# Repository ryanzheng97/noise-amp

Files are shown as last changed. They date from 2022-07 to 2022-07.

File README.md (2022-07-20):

# noise-amp

A very high gain (80db or x10000) differential AC signal amplifier (LNA, pre-amplifier, noise amplifier, etc.) board based on EEVBlog community design.

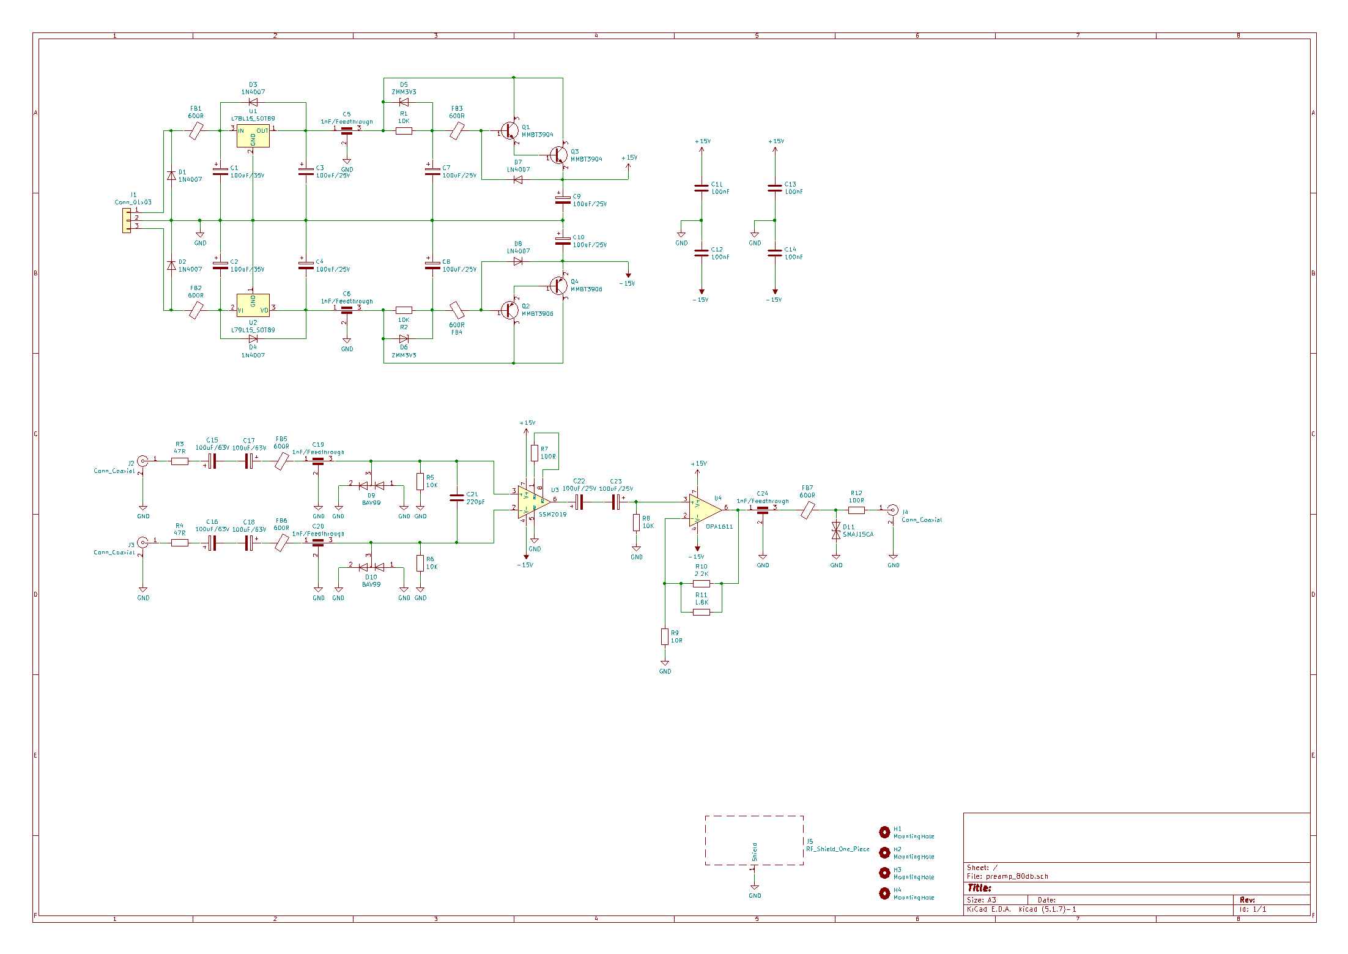
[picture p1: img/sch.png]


[Original post](https://www.eevblog.com/forum/beginners/question-about-preamp-for-measuring-noise/msg98285/#msg98285)

Board is a 100x100mm 4-layer PCB which falls into the cheap sample tier at JLCPCB or PCBWay.

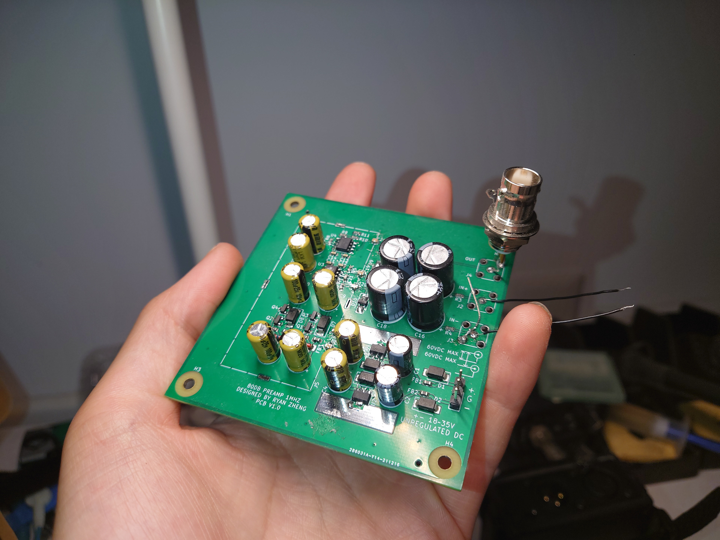
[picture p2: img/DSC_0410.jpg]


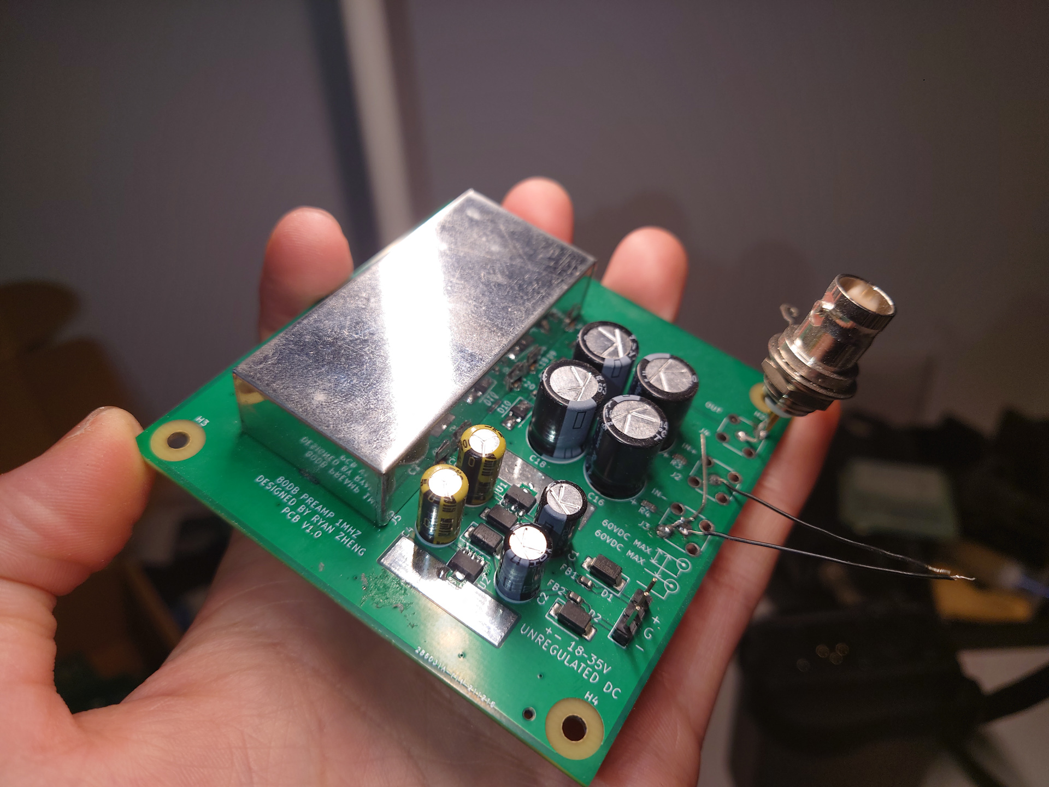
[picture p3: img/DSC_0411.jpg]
Photo of board with shielding can


# Specs
- Gain: 80db nominal
- Bandwidth: <= 1MHz
- Power: +-18 to 35VDC, unregulated
- Connector: SMA for signal input and output, 2.54mm THT pads for power input.

Test was done with a 1M to 100R resistor divider in front of the input. Signal was a sigle-ended sine wave, so one of the input is shorted to ground. Channel 3 shows original signal before resistor divider. Channel 1 shows amplified output.

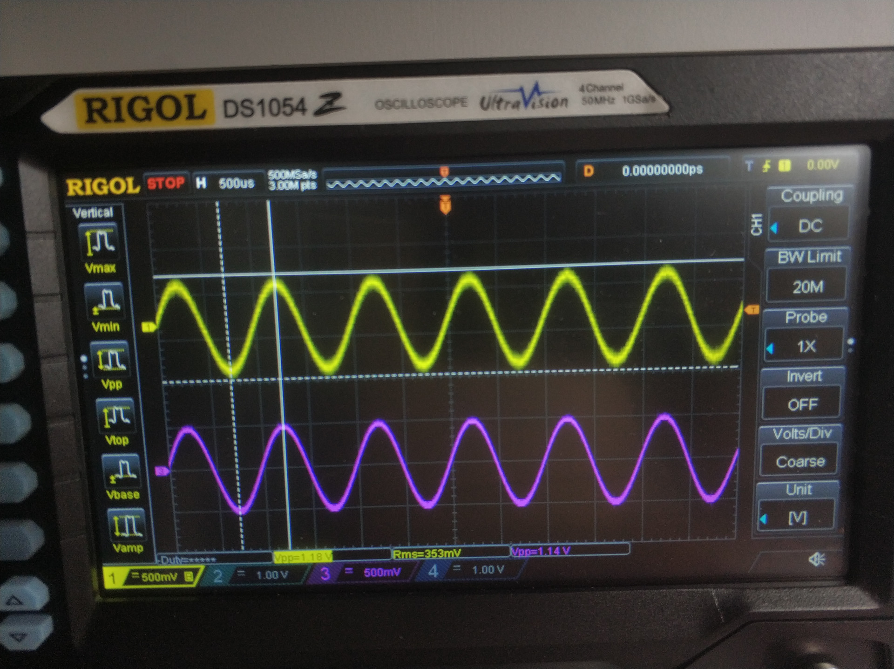
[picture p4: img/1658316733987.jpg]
Testing


# Notes
- Use high quality electrolytic capacitors
- Keep away from transformers
- You can replace op-amps with other models that you have or like
- Avoid ground loop when using
- Ground one input if using sigle-ended

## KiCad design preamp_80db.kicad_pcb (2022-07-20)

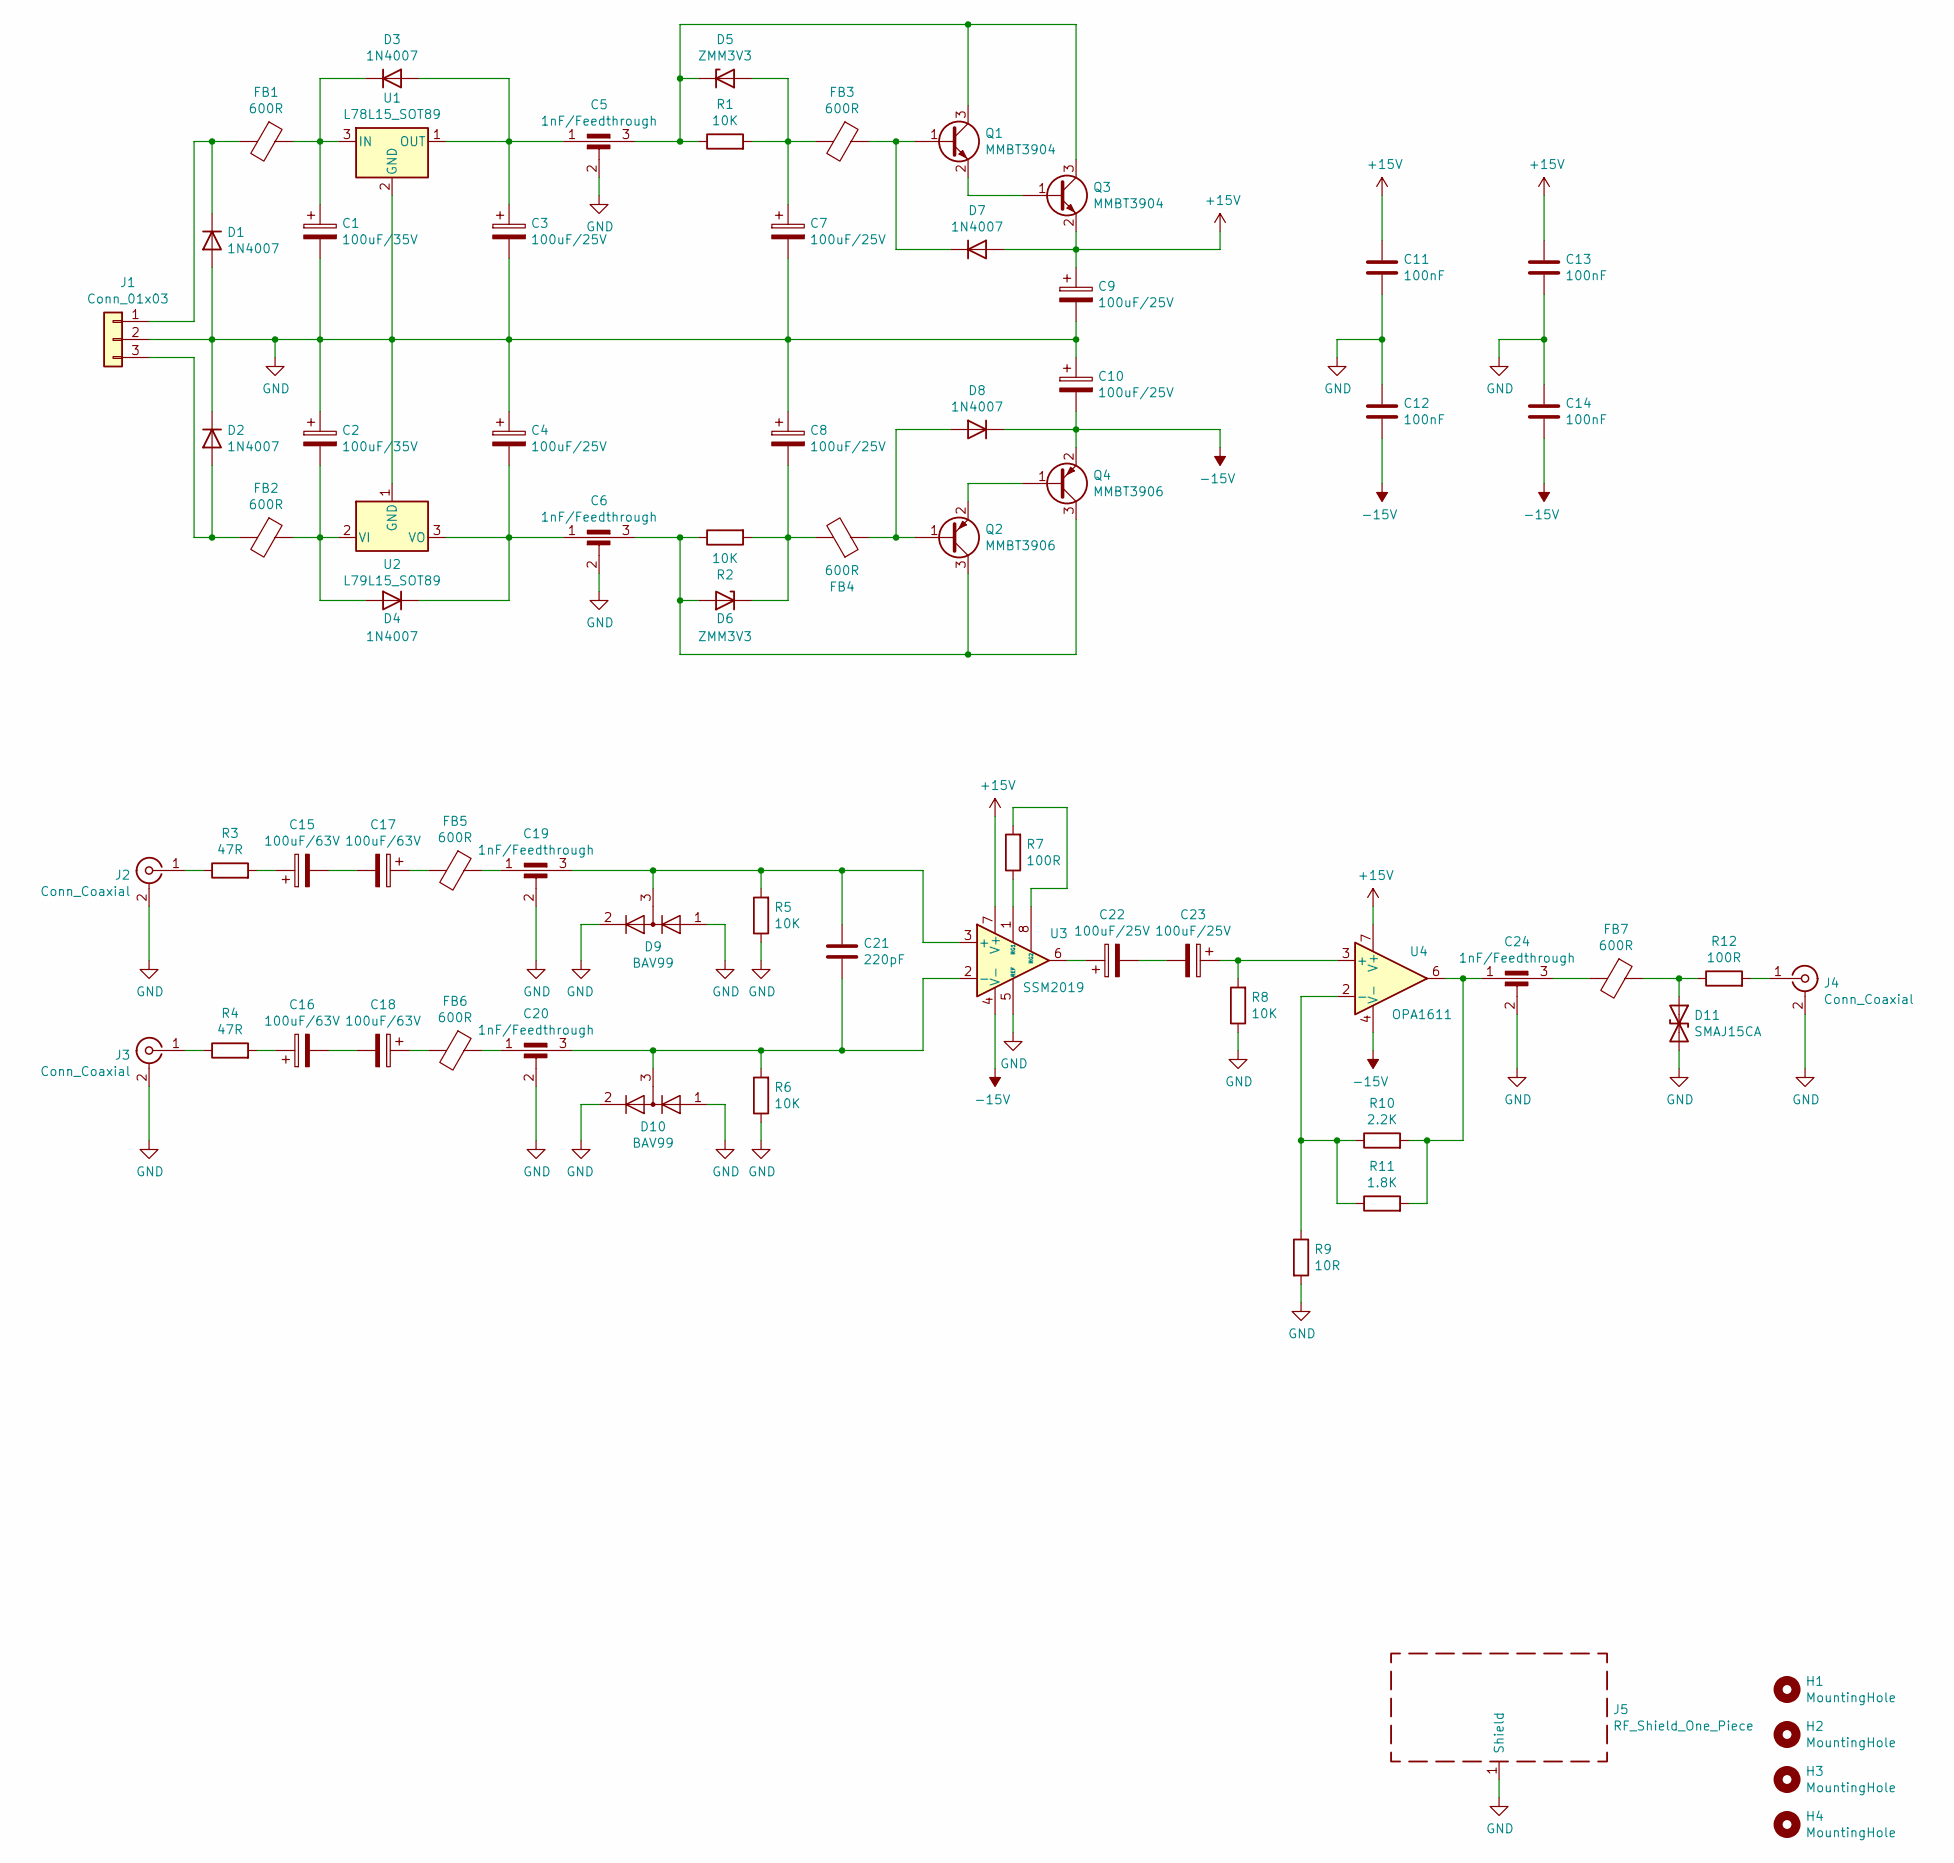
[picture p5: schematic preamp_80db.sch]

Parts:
C1, C2: 100uF/35V; CP_Radial_D6.3mm_P2.50mm
C3, C4, C7, C8, C9, C10, C22, C23: 100uF/25V; CP_Radial_D6.3mm_P2.50mm
C5, C6, C19, C20, C24: 1nF/Feedthrough; C_SMT_feedthrough_murata_0805
C11, C12, C13, C14: 100nF; C_0603_1608Metric
C15, C16, C17, C18: 100uF/63V; CP_Radial_D10.0mm_P2.50mm_P5.00mm
C21: 220pF; C_0603_1608Metric
D1, D2, D3, D4, D7, D8: 1N4007; D_SMA
D5, D6: ZMM3V3; D_MiniMELF
D9, D10: BAV99; SOT-23
D11: SMAJ15CA; D_SMA
FB1, FB2, FB3, FB4, FB5, FB6, FB7: 600R; L_0603_1608Metric
H1, H2, H3, H4: MountingHole; MountingHole_3.2mm_M3
J1: Conn_01x03; PinHeader_1x03_P2.54mm_Vertical
J2, J3, J4: Conn_Coaxial; SMA_Amphenol_132134_Vertical
J5: RF_Shield_One_Piece; Shielding_Can_THT_57x27x13mm
Q1, Q3: MMBT3904; SOT-23
Q2, Q4: MMBT3906; SOT-23
R1, R2, R5, R6, R8: 10K; R_0603_1608Metric
R3, R4: 47R; R_0603_1608Metric
R7, R12: 100R; R_0603_1608Metric
R9: 10R; R_0603_1608Metric
R10: 2.2K; R_0603_1608Metric
R11: 1.8K; R_0603_1608Metric
U1: L78L15_SOT89; SOT-89-3
U2: L79L15_SOT89; SOT-89-3
U3: SSM2019; SOIC-8_3.9x4.9mm_P1.27mm
U4: OPA1611; SOIC-8_3.9x4.9mm_P1.27mm

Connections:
+15V: C9.1, C11.1, C13.1, D7.2 (A), Q3.2 (E), U3.7 (V+), U4.7 (V+)
-15V: C10.2, C12.2, C14.2, D8.1 (K), Q4.2 (E), U3.4 (V-), U4.4 (V-)
GND: C1.2, C2.1, C3.2, C4.1, C5.2, C6.2, C7.2, C8.1, C9.2, C10.1, C11.2, C12.1, C13.2, C14.1, C19.2, C20.2, C24.2, D1.2 (A), D2.1 (K), D9.1 (K), D9.2 (A), D10.1 (K), D10.2 (A), D11.2 (A2), J1.2, J2.2 (Ext), J3.2 (Ext), J4.2 (Ext), J5.1, R5.1, R6.1, R8.1, R9.2, U1.2 (GND), U2.1 (GND), U3.5 (REF)
unnamed: C1.1, D3.1 (K), FB1.1, U1.3 (IN)
unnamed: C2.2, D4.2 (A), FB2.1, U2.2 (VI)
unnamed: C3.1, C5.1, D3.2 (A), U1.1 (OUT)
unnamed: C4.2, C6.1, D4.1 (K), U2.3 (VO)
unnamed: C5.3, D5.1 (K), Q1.3 (C), Q3.3 (C), R1.1
unnamed: C6.3, D6.2 (A), Q2.3 (C), Q4.3 (C), R2.1
unnamed: C7.1, D5.2 (A), FB3.2, R1.2
unnamed: C8.2, D6.1 (K), FB4.2, R2.2
unnamed: C15.1, R3.2
unnamed: C15.2, C17.2
unnamed: C16.1, R4.2
unnamed: C16.2, C18.2
unnamed: C17.1, FB5.2
unnamed: C18.1, FB6.2
unnamed: C19.1, FB5.1
unnamed: C19.3, C21.1, D9.3 (K), R5.2, U3.3 (+)
unnamed: C20.1, FB6.1
unnamed: C20.3, C21.2, D10.3 (K), R6.2, U3.2 (-)
unnamed: C22.1, U3.6
unnamed: C22.2, C23.2
unnamed: C23.1, R8.2, U4.3 (+)
unnamed: C24.1, R10.2, R11.2, U4.6
unnamed: C24.3, FB7.2
unnamed: D1.1 (K), FB1.2, J1.1
unnamed: D2.2 (A), FB2.2, J1.3
unnamed: D7.1 (K), FB3.1, Q1.1 (B)
unnamed: D8.2 (A), FB4.1, Q2.1 (B)
unnamed: D11.1 (A1), FB7.1, R12.1
unnamed: J2.1 (In), R3.1
unnamed: J3.1 (In), R4.1
unnamed: J4.1 (In), R12.2
unnamed: Q1.2 (E), Q3.1 (B)
unnamed: Q2.2 (E), Q4.1 (B)
unnamed: R7.1, U3.1 (RG1)
unnamed: R7.2, U3.8 (RG2)
unnamed: R9.1, R10.1, R11.1, U4.2 (-)

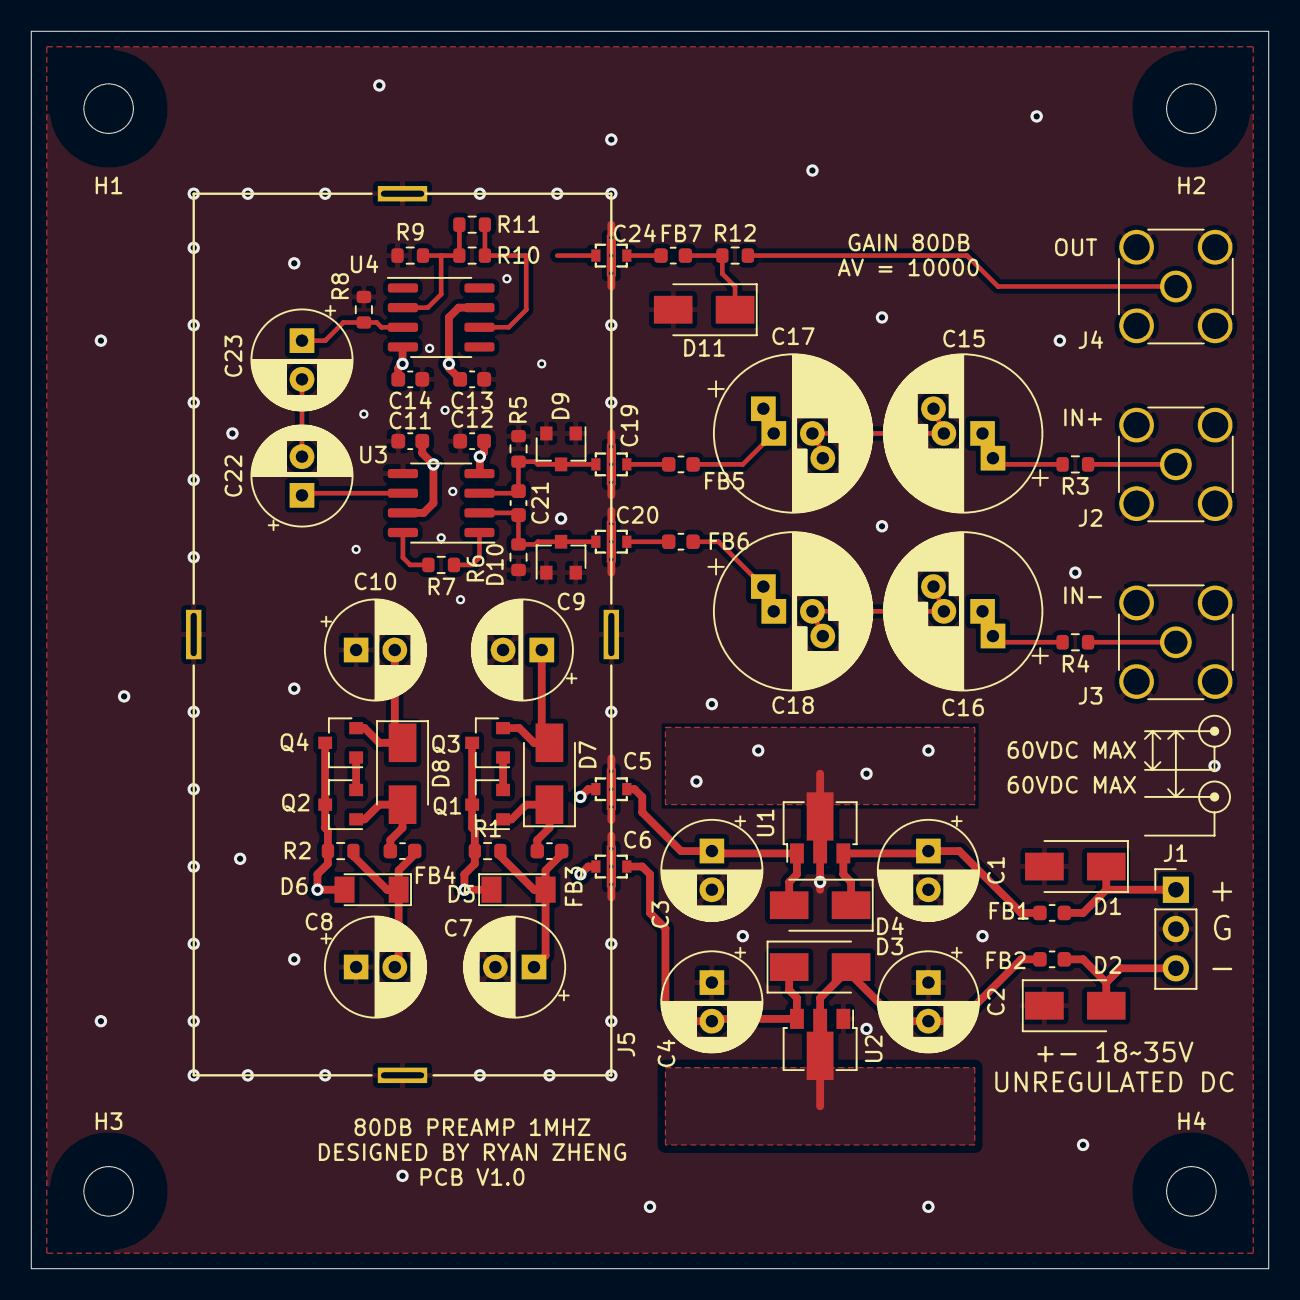
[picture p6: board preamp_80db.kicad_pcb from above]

Board: 4 copper layers, 80.0 x 80.0 mm, 71 parts (0 on the bottom side), 39 nets.
